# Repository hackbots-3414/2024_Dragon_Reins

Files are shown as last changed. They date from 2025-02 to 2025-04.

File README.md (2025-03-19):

# Dragon Reins / Dragon Scales: Custom Driver and Operator controllers
### Dragon Reins (Driver)
- Apem HF22S10 single button joystick (2)
- Apem 505-442 Switch Hardware HARNESS HF BUTTONS & DUAL (2) 
- SparkFun Electronics DEV-12640 Arduino Pro Micro
- *MAKE SURE* that Arduino IDE is in 5v mode, not 3.3v, this will cause issues

### Dragon Scales (Operator)
- Raspberry Pi Pico (original - 2020 series)
- Twidec Rocker Toggle Switch 12V / 20A Red LED Light (ASW-07DRRMZ)
- Custom printed circuit board (PCB)

### Shared
- Razer B0CCG8J9NR Green Clicky Switch Gen-3
- Razer B0973PKNRW Phantom Keycap Upgrade Set: Unique Stealth Design - Black
# button to pins

## Left Stick
| Apem Joystick Pin | Apem Wire Color | Arduino Micro Pin |
| --- | --- | --- |
| 1 | Black | GND - Right |
| 2 | Red | VCC |
| 4 | Blue | A1 |
| 6 | Yellow | A0 |
| 9 | Orange | 6 |
| 10 | White | GND - Left Bottom |

## Right Stick
| Apem Joystick Pin | Apem Wire Color | Arduino Micro Pin |
| --- | --- | --- |
| 1 | Black | GND  - Right | 
| 2 | Red | VCC |
| 4 | Blue | A3 |
| 6 | Yellow | A2 |
| 9 | Orange | 16 |
| 10 | White | GND - Left Bottom |

## Trigger Switches
| Arduino Pin | Button | Wire Color |
| --- | --- | --- |
| GND Left-Bottom | Left and Right common | White |
| 5 | Left trigger | Green |
| 3 | Right trigger | Green |

### scratch
- 0 -> purple, 16
- 1 -> blue, 14
- 2 -> green, 15
- 3 -> yellow, 2
- 4 -> orange, 8,9
- 2 -> red, VCC
- 

# libraries
- micheal adams "button" library
- the gamepad library in this repo

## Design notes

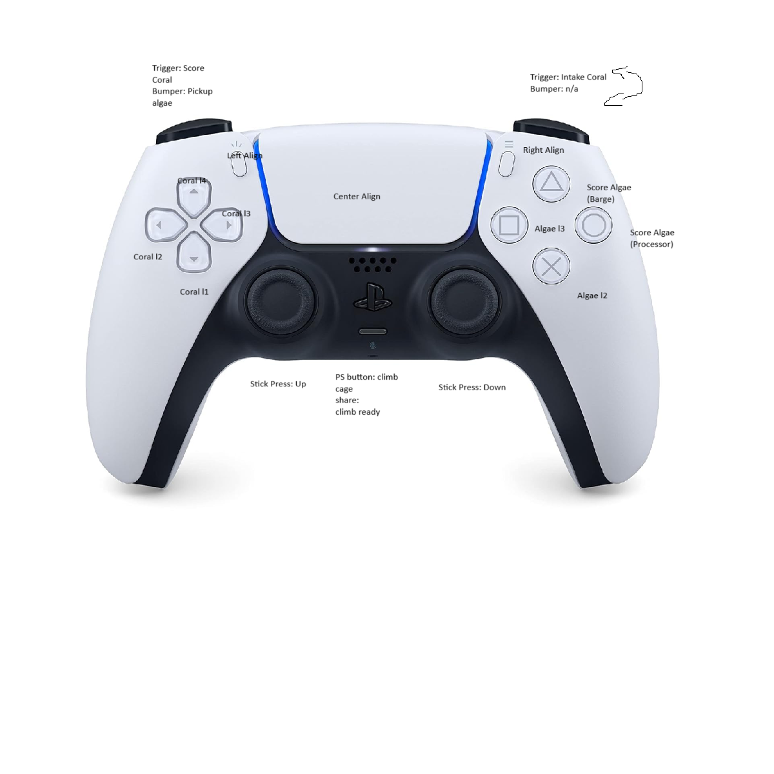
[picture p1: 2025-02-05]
playstation_operator_temp.png

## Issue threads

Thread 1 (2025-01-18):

Update DragonReins for new controller

bczdog, 2025-01-18:
Dragon Reins came out of CAD and the 3D printer.  We have 8 buttons total.  Need to ensure axes match Spektrum RC simulator controller.  Button numbering should be logical.

Closed 2025-01-18.

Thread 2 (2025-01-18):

Fix floating joystick buttons

Minejerik, 2025-01-18:
The button_common for both buttons is unconnected, meaning that they float, creating undefined behavior.

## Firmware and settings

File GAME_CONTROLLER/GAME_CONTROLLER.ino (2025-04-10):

#include <Gamepad.h>
// #include <Button.h>
#define default_deadband 5

int deadbandLY = default_deadband;
int deadbandRX = default_deadband;
int deadbandRY = default_deadband;
int deadbandLX = default_deadband;

double rightXcenter = 512;
double rightYcenter = 512;
double leftXcenter = 512;
double leftYcenter = 512;
double multiplierRX = 127/rightXcenter; //127 / 500
double multiplierRY = 127/rightYcenter;
double multiplierLX = 127/leftXcenter;
double multiplierLY = 127/leftYcenter;

// Button button0(16);
// Button button1(14);
// Button button2(15);
// Button button3(2);
// Button button4(3);
// Button button5(4);


Gamepad gp;

void setup()  {
  pinMode(5, INPUT_PULLUP); // Left Trigger
  pinMode(3, INPUT_PULLUP); // Right Trigger
  pinMode(6, INPUT_PULLUP); // left joystick button
  pinMode(16, INPUT_PULLUP); //button right joystick
  // pinMode(3, INPUT_PULLUP);
  // pinMode(4, INPUT_PULLUP);

  pinMode(A0, INPUT);
  pinMode(A1, INPUT);
  pinMode(A2, INPUT);
  pinMode(A3, INPUT);
  pinMode(8,  INPUT); //Y
  pinMode(9,  INPUT); //X
  
  // calibrate();

}

int state = 1;

void handle_buttons() {
  state ++;
  gp.setButtonState(2, !digitalRead(3)); // Right Trigger
  gp.setButtonState(3, !digitalRead(5)); //  Left Trigger
  gp.setButtonState(1, !digitalRead(6)); //remapping to better match driver preference
  gp.setButtonState(0, !digitalRead(16));
  // gp.setButtonState(4, !digitalRead(3));
  // gp.setButtonState(5, !digitalRead(4));
  // gp.setButtonState(8, !digitalRead(8));
  // gp.setButtonState(9, !digitalRead(9));
}

void loop() {
  handle_buttons();
  int lx, ly, rx, ry;
  lx = analogRead(A1);
  ly = analogRead(A0);//-leftYcenter;
  rx = analogRead(A3);//-rightXcenter;
  ry = analogRead(A2);//-rightYcenter;
  // Serial.println(ly);
  // we need to convert a 0-1000 to -127 - 127
  
  // Serial.println(multiplierLX);
  lx = floor((lx - leftXcenter) * multiplierLX);
  ly = floor((ly - leftYcenter) * multiplierLX);
  rx = floor((rx - rightXcenter) * multiplierRX);
  ry = floor((ry - rightYcenter) * multiplierRY);

  // Serial.println(ly);
  // Serial.println(rx);
  // Serial.println(ry);

  if(lx > 127) lx = 127;
  if(ly > 127) ly = 127;
  if(rx > 127) rx = 127;
  if(ry > 127) ry = 127;
  if(lx < deadbandLX && lx > -deadbandLX) lx = 0;
  if(ly < deadbandLY && ly > -deadbandLY) ly = 0;
  if(rx < deadbandRX && rx > -deadbandRX) rx = 0;
  if(ry < deadbandRY && ry > -deadbandRY) ry = 0;

  gp.setRightXaxis(-rx);
  gp.setLeftXaxis(-ly);
  gp.setRightYaxis(ry);
  gp.setLeftYaxis(lx);
  // delay(20);
}

// void calibrate()
// {
//   int lx, ly, rx, ry;
//   int i = 0;
//   while(i < 13)
//   {
//     lx = analogRead(A3);
//     ly = analogRead(A2);
//     rx = analogRead(A1);
//     ry = analogRead(A0);
//     bool validLX = lx > (leftXcenter - 100) && lx < (leftXcenter + 100);
//     bool validLY = ly > (leftYcenter - 100) && ly < (leftYcenter + 100);
//     bool validRX = rx > (rightXcenter - 100) && rx < (rightXcenter + 100);
//     bool validRY = ry > (rightYcenter - 100) && ry < (rightYcenter + 100);
//     if(validLX && validLY && validRX && validRY)
//     {
//       i++;
//       //nothing to do here!
//     }
//     else i = 0;
//     delay(20);
//   }
//   leftXcenter = lx;
//   leftYcenter = ly;
//   rightXcenter = rx;
//   rightYcenter = ry;
//   multiplierLX = (double)127 / (double)lx;
//   multiplierLY = (double)127 / (double)ly;
//   multiplierRX = (double)127 / (double)rx;
//   multiplierRY = (double)127 / (double)ry;
// }

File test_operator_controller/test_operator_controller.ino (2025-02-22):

// #include <Gamepad.h>
#include <Joystick.h>
// #include <Adafruit_NeoPixel.h>



int col_0 = 0;
int col_1 = 1;
int col_2 = 2;
int col_3 = 3;
int col_4 = 4;

int row_0 = 6;
int row_1 = 7;
int row_2 = 8;
int row_3 = 9;
int row_4 = 10;

int SW_Pin = 12;

// int pins[6] = {row_0, row_1, row_2, col_0, col_1, col_2};
int rows[5] = {row_0, row_1, row_2, row_3, row_4};
int cols[5] = {col_0, col_1, col_2, col_3, col_4};

int buttons[5][5] = {};
int sw = 0;

int ids[5][5] = {
  {1, 2, 3, 4, 5},
  {6, 7, 8, 9, 10},
  {11,12,13,14,15},
  {16,17,18,19,20},
  {21,22,23,24,25}
};


void init_pins(){
  for (int i = 0; i < 5; i++) {
    pinMode(cols[i], INPUT_PULLUP);
  }
  for (int i = 0; i < 5; i++) {
    pinMode(rows[i], INPUT);
  }
  pinMode(SW_Pin, INPUT_PULLUP);
}

void setup() {
  // put your setup code here, to run once:
  init_pins();
  Joystick.begin();
  // Serial.begin(115200);
  // for (int i = 0; i < 25; i++){
  //   buttons[i] = 0;
  // }
}

void read_pins() {
  for (int rowid = 0; rowid < 5; rowid++){
    // char temp[3];
    pinMode(rows[rowid], OUTPUT);
    digitalWrite(rows[rowid], 0);
    delay(1);
    // Serial.println("Running");
    for (int colid = 0; colid < 5; colid++){
      
      // if (!digitalRead(cols[colid])){
      //   // Serial.println("REAKKKK");
      //   // Serial.println(ids[colid][rowid]);
      // }
      if(ids[colid][rowid] != 0) {
        if (buttons[colid][rowid] != !digitalRead(cols[colid])){
          Joystick.button(ids[colid][rowid], !digitalRead(cols[colid]));
        }
        buttons[colid][rowid] = !digitalRead(cols[colid]);
        // if (!digitalRead(cols[colid])){
        //   Serial.println(ids[colid][rowid]);
        // }
      }
      // while(!digitalRead(cols[colid]));
    }
    // digitalWrite(rows[rowid], 1);
    pinMode(rows[rowid], INPUT);
    //delay(2);
    // Serial.println(String(temp));
    // }
  }
  if(sw != !digitalRead(SW_Pin)){
    Joystick.button(26, !digitalRead(SW_Pin));
  }
  sw = !digitalRead(SW_Pin);
  // Serial.println("\n\n\n\n\n\n\n\n\n\n\n");
  // delay(1000);
}

void loop() {
  // put your main code here, to run repeatedly:
  // Serial.println(digitalRead(0));
  read_pins();
  // gp.setButtonState(0, !digitalRead(0));
}

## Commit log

2025-01-18 switched joysticks
2025-01-27 Working on button matrix
2025-01-30 added schematic of hackbots operator controller
    [hackbots_operator.fzz]
2025-02-05 Updated dragon scales PCB
    [dragon_scales.fzz, hackbots_operator.fzz]
2025-02-06 new 100x100 pcb design for dragon scales
    [dragon_scales.fzz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]
2025-02-08 Updated code to have 25 buttons
    [dragon_scales_copperBottom.gbl, dragon_scales_copperTop.gtl, dragon_scales_silkTop.gto]
2025-03-15 microcontroller pin changged
2025-03-17 we swapped joystick Buttons
    [GAME_CONTROLLER.ino]
